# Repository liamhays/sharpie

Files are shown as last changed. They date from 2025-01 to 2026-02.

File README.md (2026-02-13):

# Sharpie
Sharpie is a RP2350-based development board for Sharp color (not
monochrome!) memory-in-pixel (MiP) displays, using only the PIO
peripheral. It was originally built for the Sharp LS021B7DD02 display,
but should be compatible with any color MiP device made by Sharp. For
in-depth documentation and discussion, see the relevant blog posts [on
my website](https://cryothene.neocities.org).

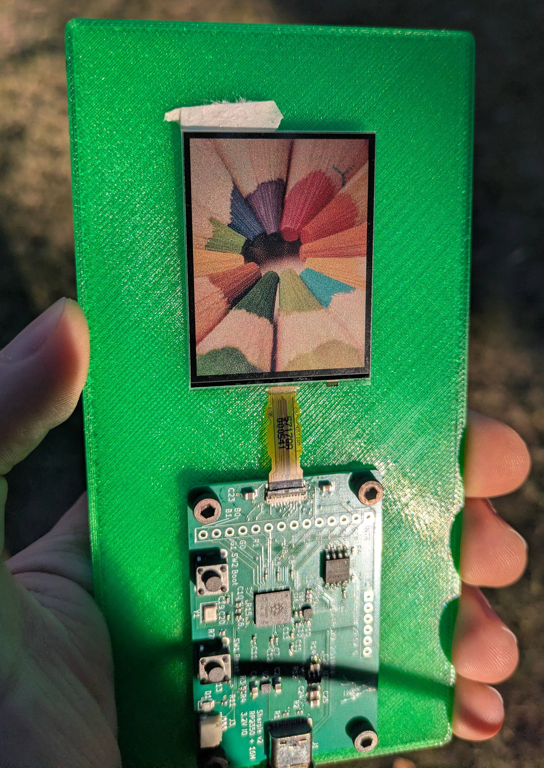
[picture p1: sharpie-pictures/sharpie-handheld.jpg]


Sharpie [plays](https://www.youtube.com/watch?v=W0dpXhKVE6Y)
[video](https://www.youtube.com/watch?v=7nzBJTZcFak) too!

## Repo contents
- `sharpie-cad`: a little bit of FreeCAD for a display/board carrier
- `sharpie-documents`: the LS021B7DD02 datasheet link on DigiKey is
  broken, this is the latest version from when it used to work
- `sharpie-formatter`: an image formatter written in Rust that can
  dither and format images to binary data, ready to be written
  directly to the display
- `sharpie-hw`: the original revision of the hardware, with an extra
  voltage regulator and the display connector wired backward
- `sharpie-hw-rev2`: the second revision of the hardware, with that
  extra regulator removed and the display connector wired correctly
  (this is the revision that works)
- `sharpie-pictures`: assorted pictures of the project
- `sharpie-rp2040`: initial proof-of-concept for the PIO display
  interface, running on an RP2040 instead of an RP2350.
- `sharpie-sw`: the current demo software for a Sharpie rev2 board,
  and a nearly perfect **reference implementation** for using this
  work with a display
- `sharpie-usb-display`: an actually useful demo, which streams 4:3
  video over USB to a Sharpie board
- `vdp-simulator`: some proof-of-concept Rust code for how you could
  make a Sega-inspired tile-based video display processor in software

## Licensing
The hardware in `sharpie-hw` and `sharpie-hw-rev2` is licensed under
the CERN-OHL-W. A copy of this license is in `sharpie-hw-rev2`.

All software in this repository is licensed under the GPLv3, available
in `LICENSE` in the root.

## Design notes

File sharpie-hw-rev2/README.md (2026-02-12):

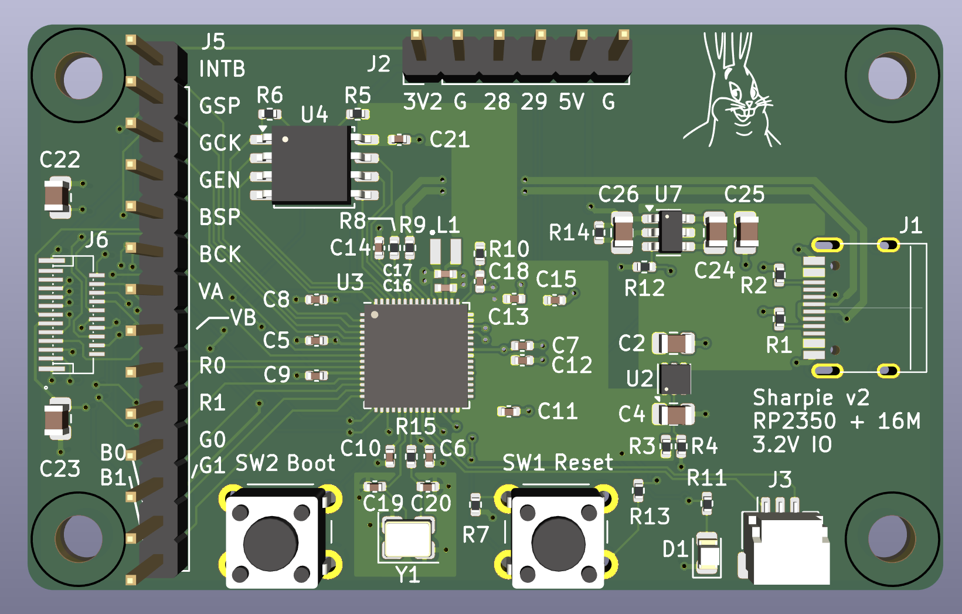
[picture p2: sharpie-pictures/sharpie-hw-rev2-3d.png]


This directory exists because I wired the connector backwards on the
original Sharpie board. Rev2 of the board also drops the 3.3V regulator,
adds the RESET pull-up that I forgot, and has a nicer looking board.

There is a lot of duplicate stuff in this directory, because I copied
straight from the original sharpie-hw design.

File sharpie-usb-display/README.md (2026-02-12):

# sharpie-usb-display
This is probably the ultimate Sharpie demo, a set of client and host
software to stream video in real time to Sharpie (and its display)
over USB. The host uses GStreamer to decode and convert a video,
then dithers and formats video frames before zstd-compressing them and
writing them to the client's USB endpoint. The client receives frames,
decompresses them, and puts them on the display.

This requires both cores on the RP2350. Instrumentation code is in
both source files if you're curious about how much time various steps
in the process require.

The host needs to be run with `--release` because the dithering is
slow (20-50 ms) in debug, but 4 ms in release. It also can't play
Matroska files, for some reason, probably because it uses a simple
GStreamer host pipeline that expects audio and video to be present
from early on.

# Notes
## Compression and transfer
lz4 is a good compression algorithm, but it doesn't get frames small
enough. zstd does, though, and it still runs plenty fast on the
RP2350.

## Video
I accidentally turned the system clock up to 200 MHz, and then I
realized that the display was still working even though the PIO and
PWM were running significantly faster. Running the PIO faster reduces
the time it takes to fill the display with new data, which helps
reduce screen tearing. Increasing the clock to 200 MHz means the
screen can theoretically run at ~24.8 fps, which beats the average
movie frame rate of 24 fps. The problem is that the USB link is
limited to about 22 fps, and increasing the frame rate also makes
flicker a little more visible (to my eyes, at least). From my testing,
the data link can always handle 21 fps, but no higher.

One change to potentially make in the future is some sort of smarter
dither algorithm that only dithers in changed regions, or something,
to reduce full-frame flicker. I think the reason that dither is so
visible is because the dithering causes every single frame to have
almost entirely different pixels. I'd also like to replace the
dithering with a SIMD implementation, and maybe these changes could
happen simultaneously.

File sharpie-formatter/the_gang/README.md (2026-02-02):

# ryuuko
These are various versions of a screenshot from an early episode of
[Kill la Kill](https://myanimelist.net/anime/18679/Kill_la_Kill), cropped
to 4:3, rescaled, and dithered. I
made these by hand with various odd tools (mostly
[dither](https://gitlab.com/efronlicht/dither)) before `sharpie-formatter`
could do all the image processing by itself, and they're here
for archival purposes.

Note in particular the dithering variants under `processed/`. I settled
on Floyd-Steinberg for `sharpie-formatter` specifically because of how
it preserved the detail in this frame.

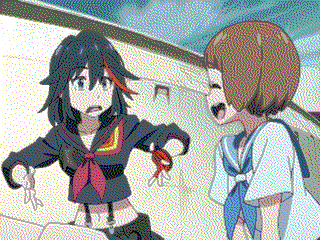
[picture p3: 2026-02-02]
sharpie-formatter/the_gang/processed/jarvis_64color.png

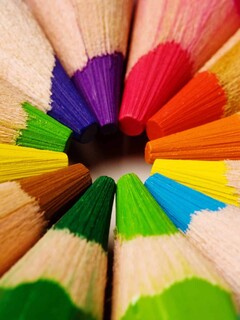
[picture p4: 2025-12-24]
sharpie-sw/pencils.jpg

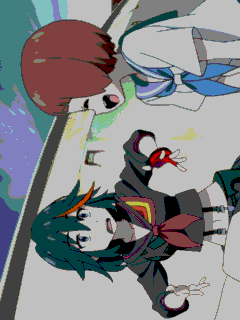
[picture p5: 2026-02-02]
sharpie-formatter/the_gang/processed/the_gang_default_formatter.png

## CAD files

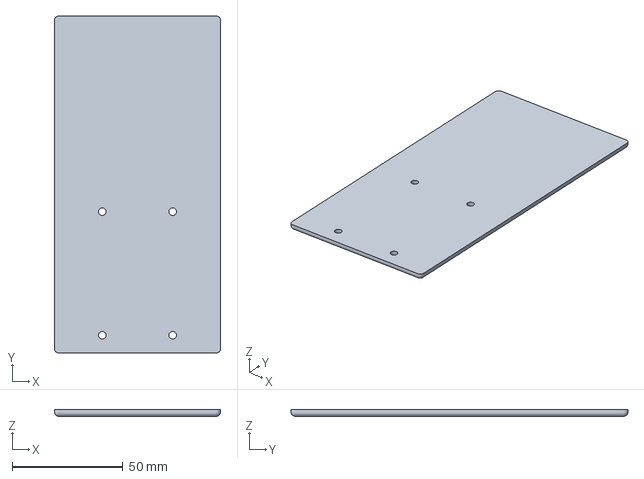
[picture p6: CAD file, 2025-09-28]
sharpie-cad/sharpie-carrier-Body.3mf
75.0 x 152.0 x 3.00 mm

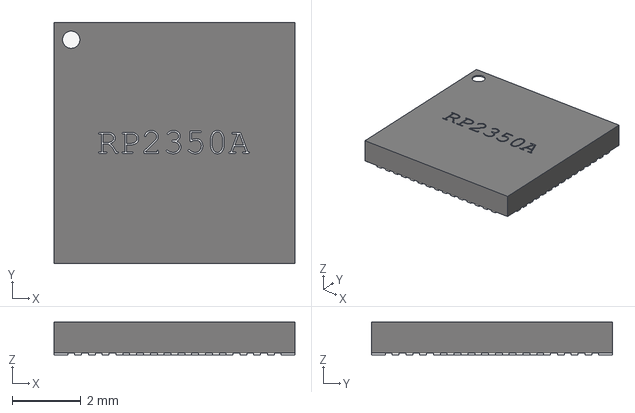
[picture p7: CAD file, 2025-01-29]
sharpie-hw-rev2/RP2350_QFN60.step
7.00 x 7.00 x 0.95 mm

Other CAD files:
sharpie-cad/sharpie-carrier.FCStd

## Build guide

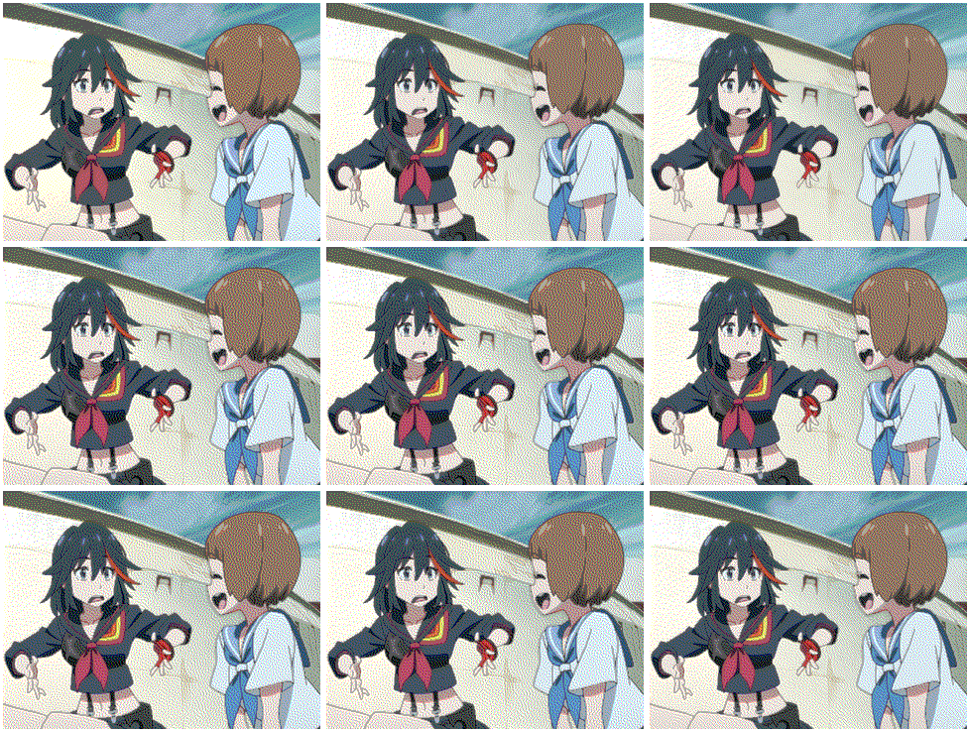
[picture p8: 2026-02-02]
sharpie-formatter/the_gang/processed/64_color_montage.png

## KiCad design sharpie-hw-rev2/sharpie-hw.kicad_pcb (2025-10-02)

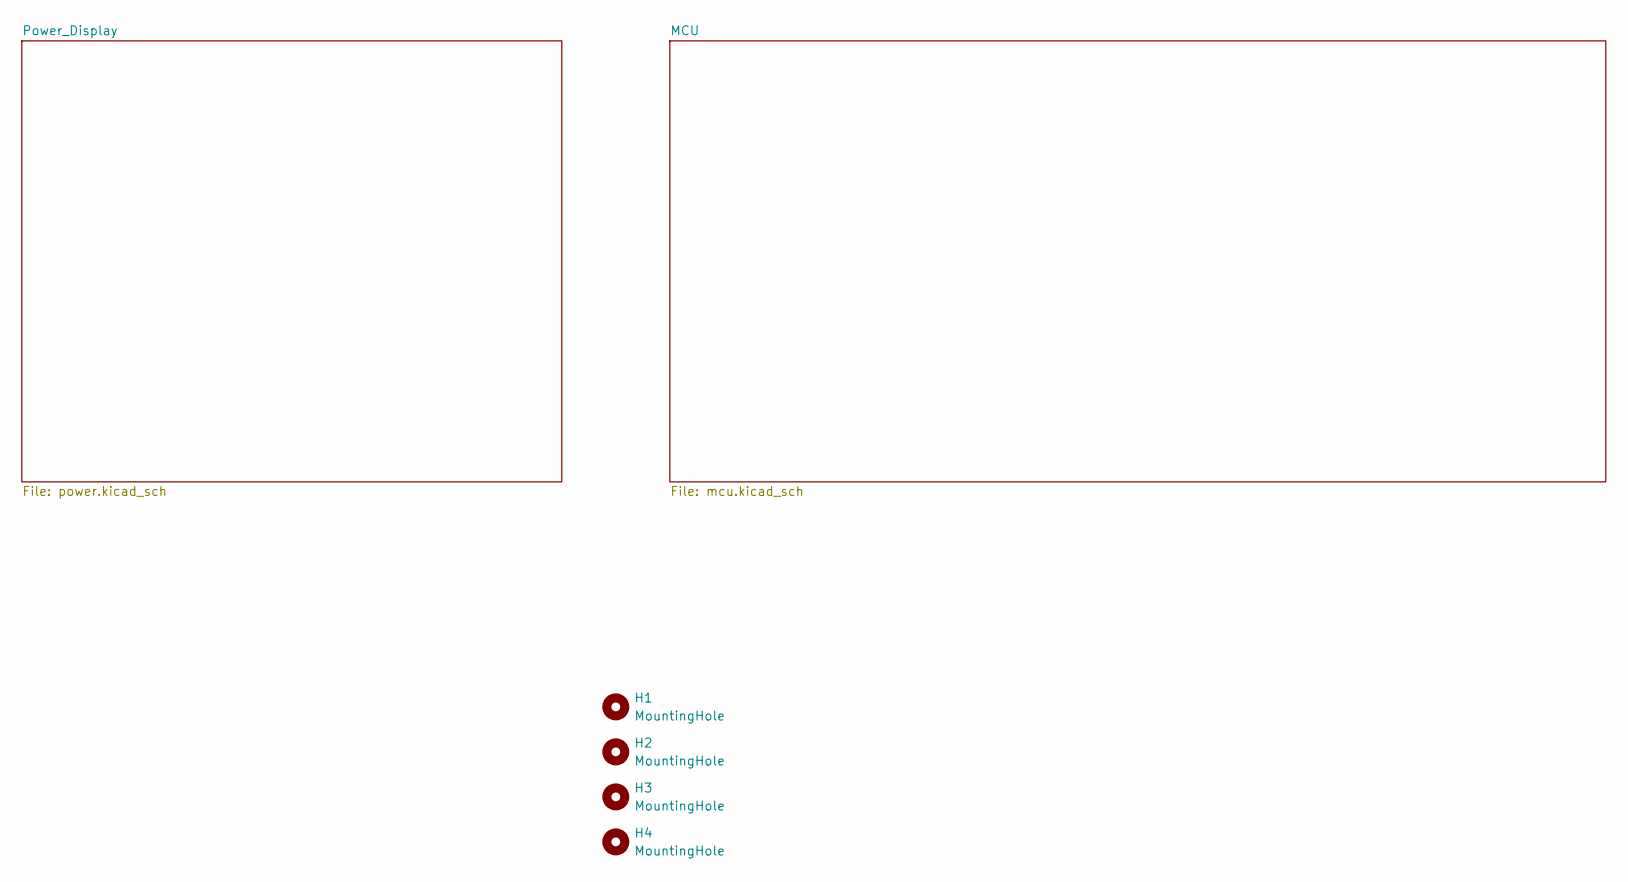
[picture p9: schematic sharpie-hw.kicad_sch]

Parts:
H1, H2, H3, H4: MountingHole; MountingHole_3.2mm_M3

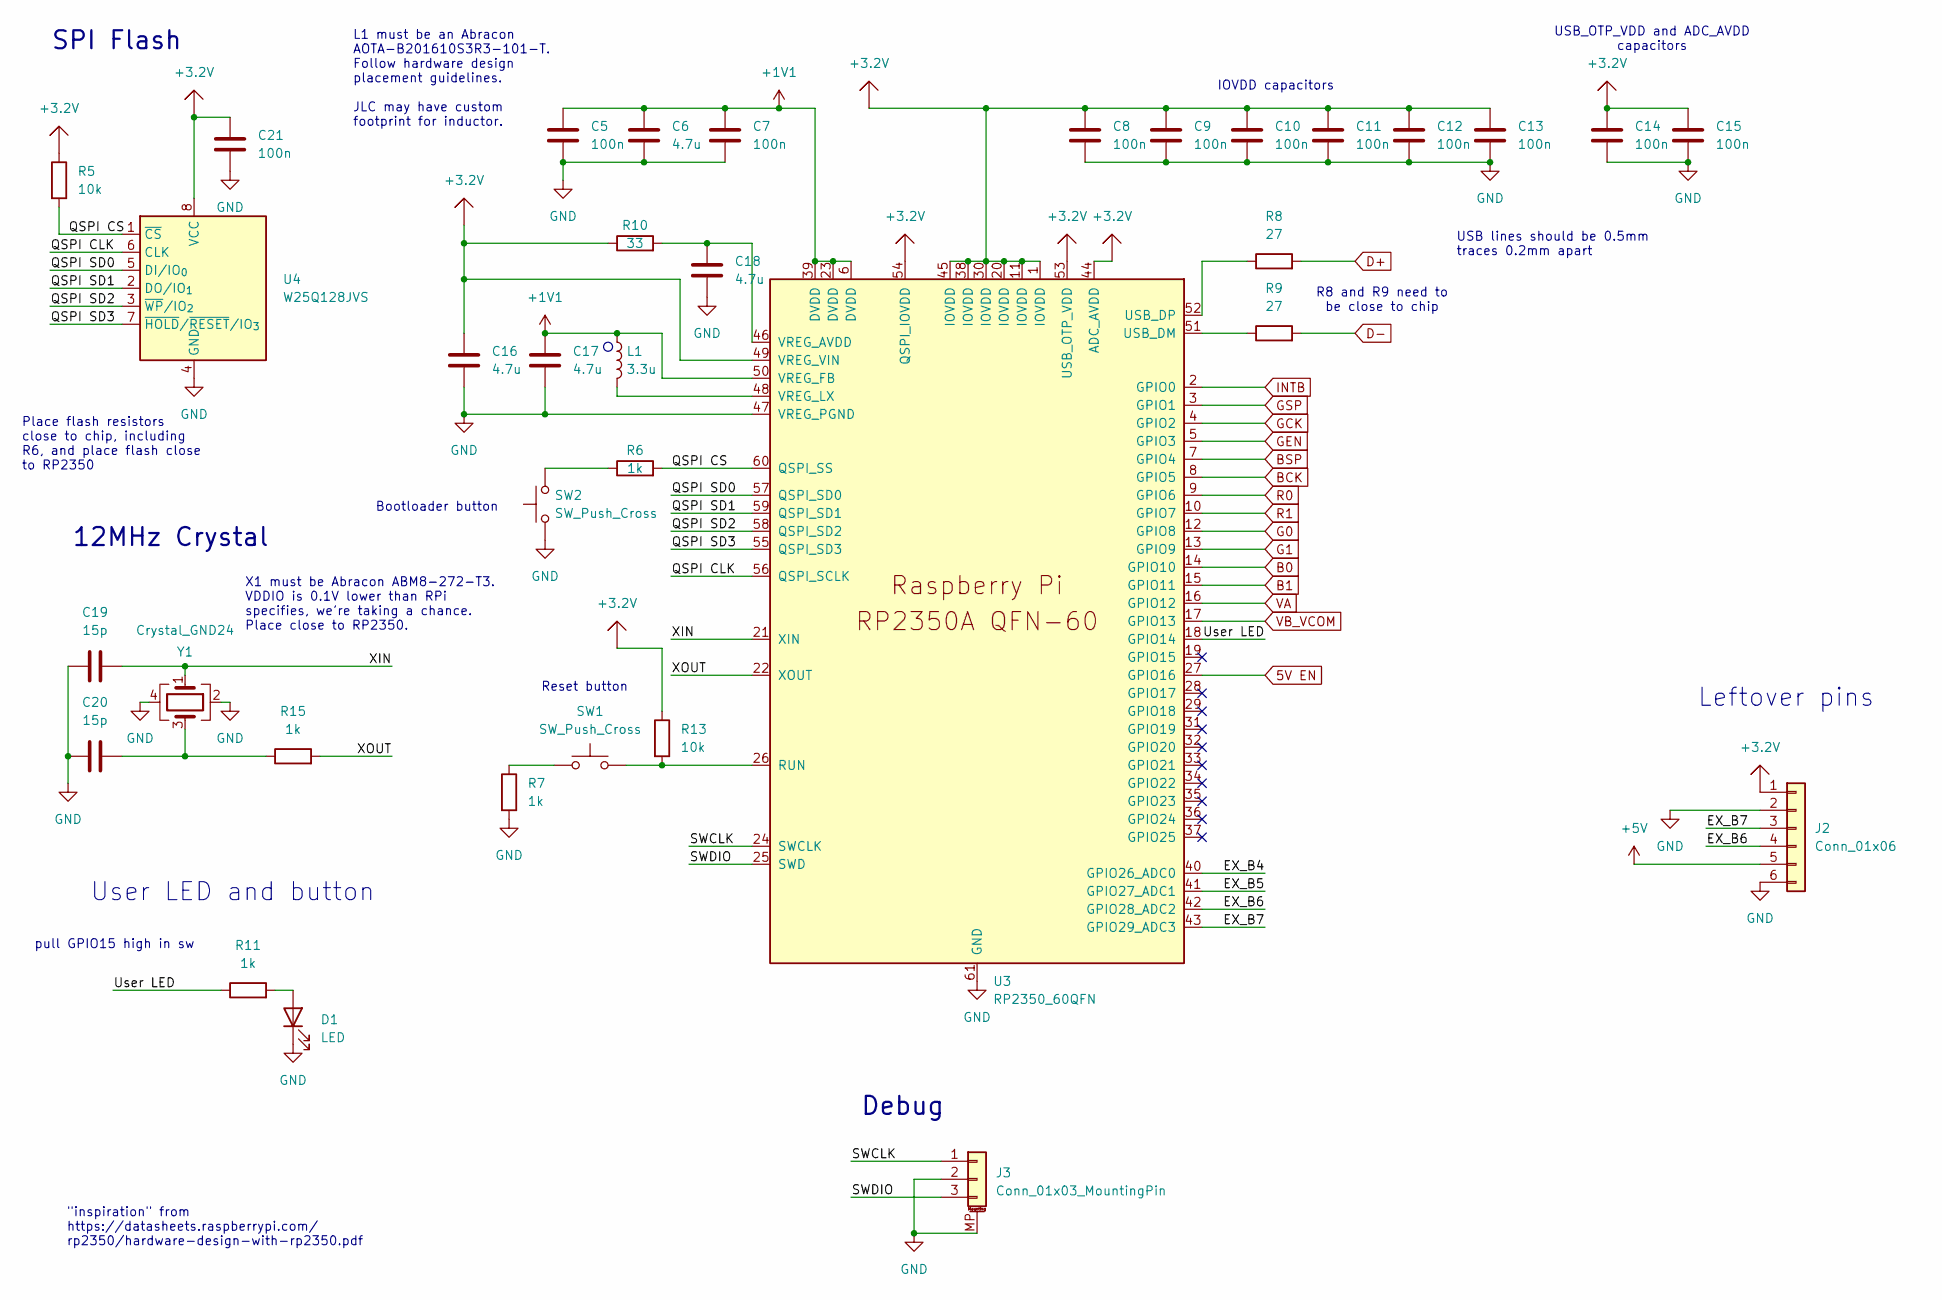
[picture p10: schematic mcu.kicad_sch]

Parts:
C5, C7, C8, C9, C10, C11, C12, C13, C14, C15, C21: 100n; C_0402_1005Metric; JLCPCB Part # C1525
C6, C18: 4.7u; C_0402_1005Metric; JLCPCB Part # C23733
C16, C17: 4.7u; C_0402_1005Metric_small_pads; JLCPCB Part # C23733
C19, C20: 15p; C_0402_1005Metric; JLCPCB Part # C1548
D1: LED; LED_0805_2012Metric; JLCPCB Part # C2297
J2: Conn_01x06; PinHeader_1x06_P2.54mm_Vertical
J3: Conn_01x03_MountingPin; JST_SH_SM03B-SRSS-TB_1x03-1MP_P1.00mm_Horizontal; JLCPCB Part # C160403
L1: 3.3u; L_pol_2016; JLCPCB Part # C42411119
R5, R13: 10k; R_0402_1005Metric; JLCPCB Part # C25744
R6, R7, R11, R15: 1k; R_0402_1005Metric; JLCPCB Part # C11702
R8, R9: 27; R_0402_1005Metric; JLCPCB Part # C25156
R10: 33; R_0402_1005Metric; JLCPCB Part # C25105
SW1, SW2: SW_Push_Cross; SW_PUSH_6mm
U3: RP2350_60QFN; RP2350-QFN-60-1EP_7x7_P0.4mm_EP3.4x3.4mm_ThermalVias; JLCPCB Part # C42411118
U4: W25Q128JVS; SOIC-8_5.3x5.3mm_P1.27mm; JLCPCB Part # C97521
Y1: Crystal_GND24; Crystal_SMD_3225-4Pin_3.2x2.5mm; JLCPCB Part # C20625731

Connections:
5V EN: U3.27 (GPIO16); also elsewhere on the board
+1V1: C5.1, C6.1, C7.1, C17.1, L1.1, U3.6 (DVDD), U3.23 (DVDD), U3.39 (DVDD), U3.50 (VREG_FB)
+3.2V: C8.1, C9.1, C10.1, C11.1, C12.1, C13.1, C14.1, C15.1, C16.1, C21.1, J2.1, R5.1, R10.1, R13.1, U3.1 (IOVDD), U3.11 (IOVDD), U3.20 (IOVDD), U3.30 (IOVDD), U3.38 (IOVDD), U3.44 (ADC_AVDD), U3.45 (IOVDD), U3.49 (VREG_VIN), U3.53 (USB_OTP_VDD), U3.54 (QSPI_IOVDD), U4.8 (VCC); also elsewhere on the board
+5V: J2.5; also elsewhere on the board
/MCU/EX_B4: U3.40 (GPIO26_ADC0)
/MCU/EX_B5: U3.41 (GPIO27_ADC1)
/MCU/EX_B6: J2.4, U3.42 (GPIO28_ADC2)
/MCU/EX_B7: J2.3, U3.43 (GPIO29_ADC3)
/MCU/QSPI CLK: U3.56 (QSPI_SCLK), U4.6 (CLK)
/MCU/QSPI CS: R5.2, R6.2, U3.60 (QSPI_SS), U4.1 (~CS)
/MCU/QSPI SD0: U3.57 (QSPI_SD0), U4.5 (DI/IO_{0})
/MCU/QSPI SD1: U3.59 (QSPI_SD1), U4.2 (DO/IO_{1})
/MCU/QSPI SD2: U3.58 (QSPI_SD2), U4.3 (~WP/IO_{2})
/MCU/QSPI SD3: U3.55 (QSPI_SD3), U4.7 (~HOLD/~RESET/IO_{3})
/MCU/SWCLK: J3.1, U3.24 (SWCLK)
/MCU/SWDIO: J3.3, U3.25 (SWD)
/MCU/User LED: R11.1, U3.18 (GPIO14)
/MCU/XIN: C19.2, U3.21 (XIN), Y1.1
/MCU/XOUT: R15.2, U3.22 (XOUT)
B0: U3.14 (GPIO10); also elsewhere on the board
B1: U3.15 (GPIO11); also elsewhere on the board
BCK: U3.8 (GPIO5); also elsewhere on the board
BSP: U3.7 (GPIO4); also elsewhere on the board
D+: R8.2; also elsewhere on the board
D-: R9.2; also elsewhere on the board
G0: U3.12 (GPIO8); also elsewhere on the board
G1: U3.13 (GPIO9); also elsewhere on the board
GCK: U3.4 (GPIO2); also elsewhere on the board
GEN: U3.5 (GPIO3); also elsewhere on the board
GND: C5.2, C6.2, C7.2, C8.2, C9.2, C10.2, C11.2, C12.2, C13.2, C14.2, C15.2, C16.2, C17.2, C18.2, C19.1, C20.1, C21.2, D1.1 (K), J2.2, J2.6, J3.2, J3.MP (MountPin), R7.2, SW2.1, U3.47 (VREG_PGND), U3.61 (GND), U4.4 (GND), Y1.2, Y1.4; also elsewhere on the board
GSP: U3.3 (GPIO1); also elsewhere on the board
INTB: U3.2 (GPIO0); also elsewhere on the board
unnamed: C20.2, R15.1, Y1.3
unnamed: D1.2 (A), R11.2
unnamed: R6.1, SW2.2
unnamed: R7.1, SW1.1
unnamed: R13.2, SW1.2, U3.26 (RUN)
unnamed: R9.1, U3.51 (USB_DM)
unnamed: R8.1, U3.52 (USB_DP)
unnamed: C18.1, R10.2, U3.46 (VREG_AVDD)
unnamed: L1.2, U3.48 (VREG_LX)
R0: U3.9 (GPIO6); also elsewhere on the board
R1: U3.10 (GPIO7); also elsewhere on the board
VA: U3.16 (GPIO12); also elsewhere on the board
VB_VCOM: U3.17 (GPIO13); also elsewhere on the board

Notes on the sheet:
Leftover pins
L1 must be an Abracon AOTA-B201610S3R3-101-T. Follow hardware design placement guidelines. JLC may have custom footprint for inductor.
IOVDD capacitors
Place flash resistors close to chip, including R6, and place flash close to RP2350
Reset button
User LED and button
12MHz Crystal
Bootloader button
"inspiration" from https://datasheets.raspberrypi.com/ rp2350/hardware-design-with-rp2350.pdf
pull GPIO15 high in sw
SPI Flash
USB lines should be 0.5mm traces 0.2mm apart
Debug
USB_OTP_VDD and ADC_AVDD capacitors
X1 must be Abracon ABM8-272-T3. VDDIO is 0.1V lower than RPi specifies, we're taking a chance. Place close to RP2350.
R8 and R9 need to be close to chip

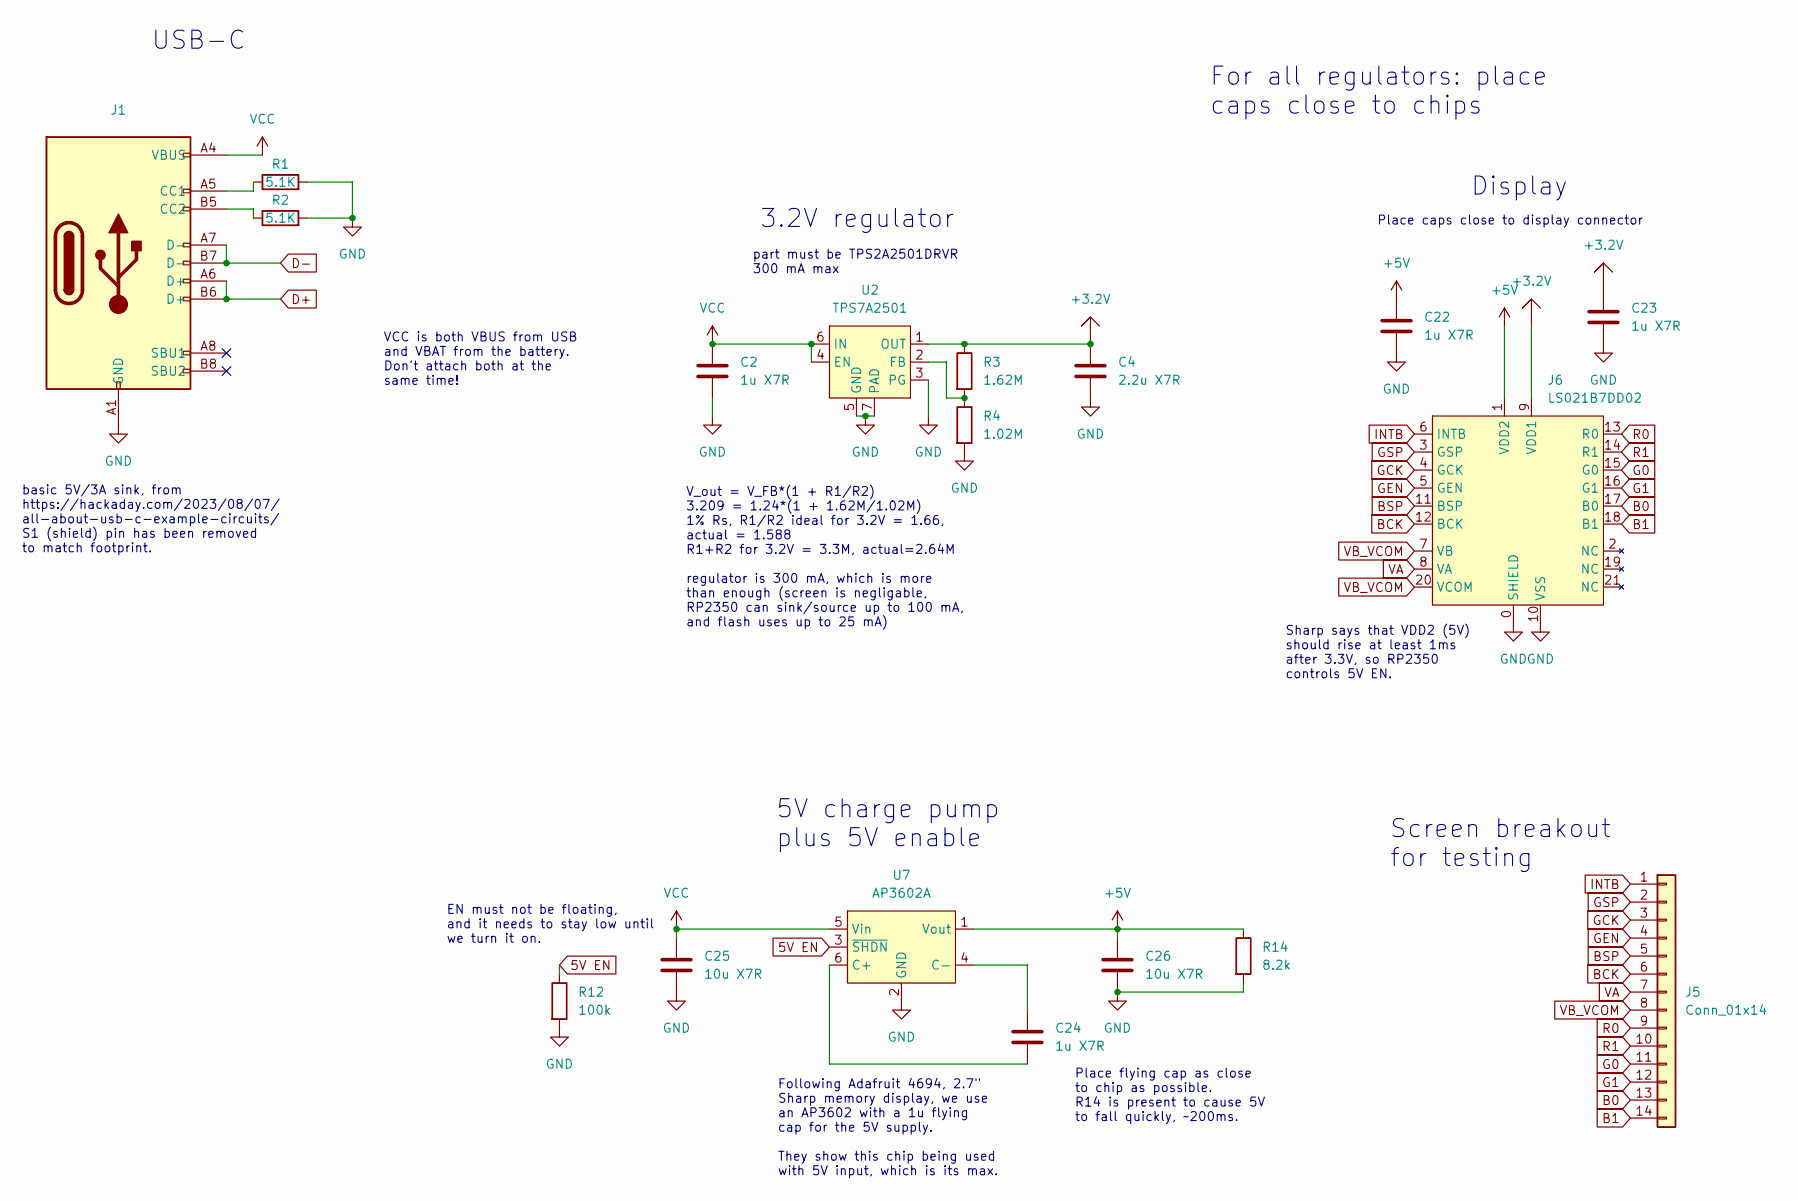
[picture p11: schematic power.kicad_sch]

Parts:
C2, C22, C23, C24: 1u X7R; C_0805_2012Metric; JLCPCB Part # C28323
C4: 2.2u X7R; C_0805_2012Metric; JLCPCB Part # C377773
C25, C26: 10u X7R; C_0805_2012Metric; JLCPCB Part # C15850
J1: TYPE-C-31-M-12; JLCPCB Part # C165948
J5: Conn_01x14; PinHeader_1x14_P2.54mm_Vertical
J6: LS021B7DD02; FPC-SMD_21P-P0.30-503566-2102
R1, R2: 5.1K; R_0402_1005Metric; JLCPCB Part # C25905
R3: 1.62M; R_0402_1005Metric; JLCPCB Part # C166525
R4: 1.02M; R_0402_1005Metric; JLCPCB Part # C26084
R12: 100k; R_0402_1005Metric; JLCPCB Part # C25741
R14: 8.2k; R_0402_1005Metric; JLCPCB Part # C25924
U2: TPS7A2501; WSON-6-1EP_2x2mm_P0.65mm_EP1x1.6mm_ThermalVias; JLCPCB Part # C2864326
U7: AP3602A; SOT-23-6; JLCPCB Part # C460358

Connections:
5V EN: R12.1, U7.3 (~SHDN); also elsewhere on the board
+3.2V: C4.1, C23.1, J6.9 (VDD1), R3.1, U2.1 (OUT); also elsewhere on the board
+5V: C22.1, C26.1, J6.1 (VDD2), R14.1, U7.1 (Vout); also elsewhere on the board
B0: J5.13, J6.17 (B0); also elsewhere on the board
B1: J5.14, J6.18 (B1); also elsewhere on the board
BCK: J5.6, J6.12 (BCK); also elsewhere on the board
BSP: J5.5, J6.11 (BSP); also elsewhere on the board
D+: J1.A6 (D+), J1.B6 (D+); also elsewhere on the board
D-: J1.A7 (D-), J1.B7 (D-); also elsewhere on the board
G0: J5.11, J6.15 (G0); also elsewhere on the board
G1: J5.12, J6.16 (G1); also elsewhere on the board
GCK: J5.3, J6.4 (GCK); also elsewhere on the board
GEN: J5.4, J6.5 (GEN); also elsewhere on the board
GND: C2.2, C4.2, C22.2, C23.2, C25.2, C26.2, J1.A1 (GND), J1.A12 (GND), J1.B1 (GND), J1.B12 (GND), J6.0 (SHIELD), J6.10 (VSS), R1.2, R2.2, R4.2, R12.2, R14.2, U2.3 (PG), U2.5 (GND), U2.7 (PAD), U7.2 (GND); also elsewhere on the board
GSP: J5.2, J6.3 (GSP); also elsewhere on the board
INTB: J5.1, J6.6 (INTB); also elsewhere on the board
unnamed: J1.A5 (CC1), R1.1
unnamed: J1.B5 (CC2), R2.1
unnamed: R3.2, R4.1, U2.2 (FB)
unnamed: C24.1, U7.6 (C+)
unnamed: C24.2, U7.4 (C-)
R0: J5.9, J6.13 (R0); also elsewhere on the board
R1: J5.10, J6.14 (R1); also elsewhere on the board
VA: J5.7, J6.8 (VA); also elsewhere on the board
VB_VCOM: J5.8, J6.7 (VB), J6.20 (VCOM); also elsewhere on the board
VCC: C2.1, C25.1, J1.A4 (VBUS), J1.A9 (VBUS), J1.B4 (VBUS), J1.B9 (VBUS), U2.4 (EN), U2.6 (IN), U7.5 (Vin)

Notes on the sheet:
basic 5V/3A sink, from https://hackaday.com/2023/08/07/ all-about-usb-c-example-circuits/ S1 (shield) pin has been removed to match footprint.
Place flying cap as close to chip as possible. R14 is present to cause 5V to fall quickly, ~200ms.
V_out = V_FB*(1 + R1/R2) 3.209 = 1.24*(1 + 1.62M/1.02M) 1% Rs, R1/R2 ideal for 3.2V = 1.66, actual = 1.588 R1+R2 for 3.2V = 3.3M, actual=2.64M regulator is 300 mA, which is more than enough (screen is negligable, RP2350 can sink/source up to 100 mA, and flash uses up to 25 mA)
EN must not be floating, and it needs to stay low until we turn it on.
3.2V regulator
Display
VCC is both VBUS from USB and VBAT from the battery. Don't attach both at the same time!
Place caps close to display connector
For all regulators: place caps close to chips
part must be TPS2A2501DRVR 300 mA max
5V charge pump plus 5V enable
Following Adafruit 4694, 2.7" Sharp memory display, we use an AP3602 with a 1u flying cap for the 5V supply. They show this chip being used with 5V input, which is its max.
Sharp says that VDD2 (5V) should rise at least 1ms after 3.3V, so RP2350 controls 5V EN.
Screen breakout for testing
USB-C

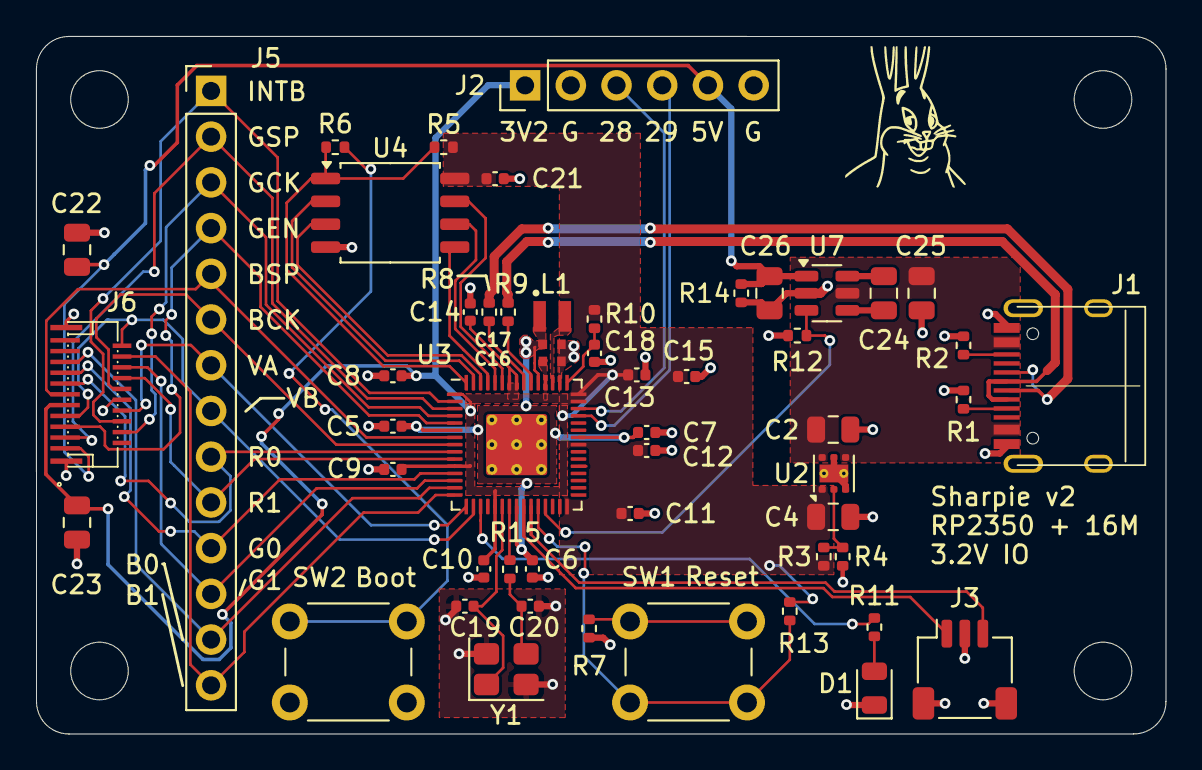
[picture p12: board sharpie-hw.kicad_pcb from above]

Board: 2 copper layers, 62.8 x 38.8 mm, 57 parts (0 on the bottom side), 49 nets.

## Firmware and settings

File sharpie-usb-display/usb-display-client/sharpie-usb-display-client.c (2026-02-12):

#include <stdio.h>
#include <stdlib.h>
#include <string.h>

#include "pico/stdlib.h"
#include "pico/multicore.h"
#include "hardware/clocks.h"
#include "hardware/uart.h"
#include "hardware/pio.h"
#include "hardware/dma.h"
#include "hardware/pwm.h"

#include "sharpie-vertical.pio.h"
#include "sharpie-gen.pio.h"
#include "sharpie-horiz-data.pio.h"
// tinyusb source

#include "RP2350.h"

// tusb_config.h is included by tusb.h. we've configured CMake so that
// it knows to make tusb_config.h available.
#include "bsp/board_api.h"
#include "tusb.h"

#include "zstd.h"

#define BUFSIZE (76800)
#define RUNS (300)

typedef struct compressed_buffer {
  uint8_t data[BUFSIZE];
  uint32_t compressed_size;
} compressed_buffer_t;

// TODO: write directly into the buffers instead of inputbuf
uint8_t inputbuf[BUFSIZE];
compressed_buffer_t compressed_buffer0 = {0};
compressed_buffer_t compressed_buffer1 = {0};
uint8_t framebuffer[BUFSIZE];


// USB RX buffer is 32768, TX buffer is 64

const int led_pin = 14;
const int five_volt_en = 16;
const int va_pin = 12;
const int vb_vcom_pin = 13;

uint pwm_slice;

void error_handler() {
  while (1) {
    gpio_put(led_pin, 1);
    sleep_ms(500);
    gpio_put(led_pin, 0);
    sleep_ms(500);
  }
}


uint vertical_sm = 0;
uint gen_sm = 1;
uint horiz_data_sm = 2;

PIO full_frame_pio = pio0;

uint vertical_offset;
uint gen_offset;
uint horiz_data_offset;


uint32_t global_32bit_zero = 0;
int image_pixels_channel;
int image_pixels_zero_channel;
int compressed_data_copy_channel;

void send_full_frame_image(const unsigned char* source) {
  
  // this DMA stream sends the image, and chains to `image_zero_c`,
  // which sends 120 bytes of zeros to close out the image. a change
  // to make in the future is to include these zeros in the image
  // buffer, so a second stream isn't necessary.
  dma_channel_config image_c = dma_channel_get_default_config(image_pixels_channel);
  channel_config_set_read_increment(&image_c, true); // increment reads
  channel_config_set_write_increment(&image_c, false); // no increment writes (into the FIFO)
  channel_config_set_transfer_data_size(&image_c, DMA_SIZE_32); // four byte transfers (one byte doesn't work)
  channel_config_set_dreq(&image_c, pio_get_dreq(full_frame_pio, horiz_data_sm, true)); // true for sending data to SM
  channel_config_set_chain_to(&image_c, image_pixels_zero_channel); // chain to zero channel to start zero channel when this finishes
  dma_channel_configure(image_pixels_channel, &image_c,
			&full_frame_pio->txf[horiz_data_sm], // destination (TX FIFO of SM 2)
		        source, // source 
			19200, // transfer size = 320*240/4 = 19200
			true); // start now



  dma_channel_config image_zero_c = dma_channel_get_default_config(image_pixels_zero_channel);
  channel_config_set_read_increment(&image_zero_c, false); // just send zeros
  channel_config_set_write_increment(&image_zero_c, false); // write into FIFO
  channel_config_set_transfer_data_size(&image_zero_c, DMA_SIZE_32);
  channel_config_set_dreq(&image_zero_c, pio_get_dreq(full_frame_pio, horiz_data_sm, true));
  dma_channel_configure(image_pixels_zero_channel, &image_zero_c,
			&full_frame_pio->txf[horiz_data_sm],
			&global_32bit_zero,
			120/4,
			false); // wait for chain start


  
  // transmit image
  full_frame_pio->irq_force = 0b1;
}

void init_full_frame_pio() {
  // add programs for the full-frame (no partial update) PIO
  vertical_offset = pio_add_program(full_frame_pio, &sharpie_vertical_program);
  if (vertical_offset < 0) {
    printf("failed to add sharpie_vertical_program\n");
    error_handler();
  }
  
  // init GEN state machine
  gen_offset = pio_add_program(full_frame_pio, &sharpie_gen_program);
  if (gen_offset < 0) {
    printf("failed to add sharpie_gen_program\n");
    error_handler();
  }
  
  
  // init horiz/data state machine
  horiz_data_offset = pio_add_program(full_frame_pio,
				      &sharpie_horiz_data_program);
  if (horiz_data_offset < 0) {
    printf("failed to add sharpie_horiz_data_program\n");
    error_handler();
  }

}

void reset_full_frame_pio() {
  // init all three state machines. we would prefer to not do this
  // every time but it takes a decent amount of consideration to make that work.

  // INTB on 0, GSP on 1, GCK on 2
  sharpie_vertical_pio_init(full_frame_pio, vertical_sm, vertical_offset, 0);
  // GEN on pin 3, start state machine
  sharpie_gen_pio_init(full_frame_pio, gen_sm, gen_offset, 3);
  // BSP on pin 4, BCK on pin 5, data from pin 6 to 11 inclusive
  sharpie_horiz_data_pio_init(full_frame_pio, horiz_data_sm, horiz_data_offset, 4, 6);
  
  // charge the vertical state machine, it's waiting for irq 0
  // the number you put in its FIFO is the number of times the loop
  // will run, minus 1
  pio_sm_put(full_frame_pio, vertical_sm, 321); // run 321 times for 648 h/l total
  
  // GEN: run 5 times (counter value + 1)
  pio_sm_put(full_frame_pio, gen_sm, 639); // this should be 639 for 640 high pulses
  pio_sm_exec(full_frame_pio, gen_sm, pio_encode_pull(false, false)); // just a basic pull
  pio_sm_exec(full_frame_pio, gen_sm, pio_encode_mov(pio_x, pio_osr)); // mov x, osr
  // GEN counter is now charged
  
  // horiz-data: charge X, make a backup in ISR (unused by any other part of the code)
  pio_sm_put(full_frame_pio, horiz_data_sm, 59); // we'll get a total of 2(x+1)+4 h/l so this should be 59 => 2(59+1)+4 = 124
  pio_sm_exec(full_frame_pio, horiz_data_sm, pio_encode_pull(false, false));  // pull
  pio_sm_exec(full_frame_pio, horiz_data_sm, pio_encode_out(pio_isr, 32)); // out isr, 32 (make backup of counter value and clear OSR for autopull)
  pio_sm_exec(full_frame_pio, horiz_data_sm, pio_encode_mov(pio_x, pio_isr)); // mov x, isr (load X with counter)
  // charge Y for total loop counter
  pio_sm_put(full_frame_pio, horiz_data_sm, 640); // should be 640 for 641 loops (see 6-3-2, the last loop has data all zeros, which is why we have a chained DMA channel below)
  pio_sm_exec(full_frame_pio, horiz_data_sm, pio_encode_pull(false, false)); // pull
  pio_sm_exec(full_frame_pio, horiz_data_sm, pio_encode_out(pio_y, 32)); // out y, 32 (also clears OSR)

  // restart all state machine clocks
  //pio_clkdiv_restart_sm_mask(full_frame_pio, 0b111); // restart state machines
  
}



const uint32_t sys_clock_hz = 200000000;
// we know exactly how the PIO works, so we can use this for an easy
// final delay in the core1 loop
const uint32_t one_gck_hl_us = (1./((float)sys_clock_hz/3100.)) * 4e6;


int data_ready_doorbell;
// the framebuffer ID with the newest data in it
volatile int newest_compressed_buffer = 0;

void core1_entry() {
  CoreDebug->DEMCR |= CoreDebug_DEMCR_TRCENA_Msk;
  
  DWT->CTRL |= DWT_CTRL_CYCCNTENA_Msk;

  char str[100];
  uint32_t count = 0;
  while (true) {
    if (multicore_doorbell_is_set_current_core(data_ready_doorbell)) {
      //gpio_put(led_pin, !gpio_get(led_pin));
      multicore_doorbell_clear_current_core(data_ready_doorbell);

      //multicore_doorbell_set_other_core(data_processing_doorbell);
      DWT->CYCCNT = 0;
      uint32_t compressed_size = 0;
      size_t dsize = 0;
      // the minute the frame size drops down to like 2000 bytes, the
      // screen goes awry, because the PIO is getting reset during a
      // frame (data transfer outpaces data transmission).
      if (newest_compressed_buffer == 0) {
	dsize = ZSTD_decompress(framebuffer, 76800,
				compressed_buffer0.data,
				compressed_buffer0.compressed_size);

	compressed_size = compressed_buffer0.compressed_size;
      } else if (newest_compressed_buffer == 1) {
	dsize = ZSTD_decompress(framebuffer, 76800,
				compressed_buffer1.data,
				compressed_buffer1.compressed_size);
	compressed_size = compressed_buffer1.compressed_size;
      }
      
      uint32_t c = DWT->CYCCNT;
      // if we get a really short frame, the decompression time is so
      // low that we end up resetting the PIO during a frame, and the
      // screen goes dark. if we instead always make sure that the PIO
      // is done before resetting it, then the screen always holds the
      // correct frame.
      while (dma_channel_is_busy(image_pixels_channel) ||
	     dma_channel_is_busy(image_pixels_zero_channel));
      // after the DMA ends, we have five GCK h/ls to wait for. add
      // one more for good measure
      sleep_us(one_gck_hl_us*6);
      reset_full_frame_pio();
      send_full_frame_image(framebuffer);

      /*sprintf(str, "frame %lu: decompression time for %lu bytes=>%lu bytes: %f\r\n",
	      count, compressed_size, dsize, ((float)c/200e6));
      uart_puts(uart1, str);*/
      //count++;
      //multicore_doorbell_clear_other_core(data_processing_doorbell);
    }
  }

}

void main() {
  // there doesn't appear to be any issues at 150 MHz except for
  // excessive screen tearing sometimes. upping this to 200 MHz means
  // that the display transmission is faster, so tearing is less
  // visible (also, that much of a change should put the display
  // signals out of spec, but that doesn't seem to happen).

  set_sys_clock_hz(sys_clock_hz, true);
  // enable cycle counter
  CoreDebug->DEMCR |= CoreDebug_DEMCR_TRCENA_Msk;
  
  DWT->CTRL |= DWT_CTRL_CYCCNTENA_Msk;

  // init multicore
  data_ready_doorbell = multicore_doorbell_claim_unused((1 << NUM_CORES) - 1, true);
  multicore_doorbell_clear_current_core(data_ready_doorbell);
  
  multicore_launch_core1(core1_entry);
  
  // init display stuff
  gpio_init(five_volt_en);
  gpio_set_dir(five_volt_en, GPIO_OUT);

  gpio_init(led_pin);
  gpio_set_dir(led_pin, GPIO_OUT);

  // this is a shortened version of the init procedure in sharpie-sw
  gpio_put(five_volt_en, 1);
  sleep_ms(3);

  pwm_slice = pwm_gpio_to_slice_num(va_pin); // channel 6A (slice 6)

  // using pwm_config doesn't seem to work
  gpio_set_function(va_pin, GPIO_FUNC_PWM);
  gpio_set_function(vb_vcom_pin, GPIO_FUNC_PWM);
  pwm_set_clkdiv(pwm_slice, 250);
  int wrap = 10000;
  pwm_set_wrap(pwm_slice, wrap);
  // VB/VCOM needs to start first, with VA 180 degrees out of phase,
  // so we set the counter halfway so that the outputs are initially
  // on. the second output is also inverted to make the phase shift.
  pwm_set_counter(pwm_slice, wrap/2);
  pwm_set_chan_level(pwm_slice, PWM_CHAN_A, wrap/2);
  pwm_set_chan_level(pwm_slice, PWM_CHAN_B, wrap/2);
  // invert output B (VB/VCOM)
  pwm_set_output_polarity(pwm_slice, false, true);
  pwm_set_enabled(pwm_slice, true);

  // wait at least two VB/VCOM cycles (at 60 Hz one cycle is 16 ms)
  //
  // Datasheet shows at least 1.5 cycles before sending data
  sleep_ms(60);

  
  // set up debug uart
  gpio_set_function(26, UART_FUNCSEL_NUM(uart1, 26));
  gpio_set_function(27, UART_FUNCSEL_NUM(uart1, 27));
  uart_init(uart1, 115200);
  uart_puts(uart1, "init\r\n");

  char str[100];

  
  tusb_rhport_init_t dev_init = {
    .role = TUSB_ROLE_DEVICE,
    .speed = TUSB_SPEED_AUTO
  };
  board_init();
  tusb_init(0, &dev_init);

  bool frame_in_progress = false;
  uint32_t count = 0;
  uint32_t compressed_size = 0;
  
  init_full_frame_pio();
  image_pixels_channel = dma_claim_unused_channel(true); // true -> required
  if (image_pixels_channel < 0) {
    printf("failed to claim red dma channel\n");
    error_handler();
  }

  image_pixels_zero_channel = dma_claim_unused_channel(true);
  if (image_pixels_zero_channel < 0) {
    printf("failed to claim red dma zero channel\n");
    error_handler();
  }

  compressed_data_copy_channel = dma_claim_unused_channel(true);
  if (compressed_data_copy_channel < 0) {
    printf("failed to claim compressed data copy channel\n");
    error_handler();
  }

  // reset and send take 61 us
  /*DWT->CYCCNT = 0;
  uint32_t c = DWT->CYCCNT;

  sprintf(str, "finished, took %lu cycles = %f sec\r\n",
		c, ((float)c/sys_clock_hz));
  uart_puts(uart1, str);*/
  
  while (1) {
    tud_task();

    if (!tud_vendor_mounted()) {
      continue;
    }

    uint32_t avail = tud_vendor_available();
    
    if (avail != 0) {

      if (!frame_in_progress) {
	frame_in_progress = true;
	DWT->CYCCNT = 0;
	// read initial 4 byte size value
	compressed_size = 0;
	count = 0;
	// start by reading just the number of bytes in this compressed frame
	count += tud_vendor_read(inputbuf, 4);
	memcpy(&compressed_size, inputbuf, 4);
	/*sprintf(str, "going to read %lu bytes\r\n", compressed_size);
	uart_puts(uart1, str);*/
      }

      // then try to read as many as we can get
      count += tud_vendor_read(inputbuf + count, compressed_size);
      if (count == compressed_size + 4) {

	uint32_t end = DWT->CYCCNT;

	// this loop can always be at most one frame ahead of the
	// decompression loop
	
	if (newest_compressed_buffer == 0) {
	  // if we last wrote to 0, use 1
	  //
	  // note that we don't need to copy the count bytes.
	  //
	  // using DMA here would probably save about 20000 cycles,
	  // for maybe a .1-.2 difference in fps
	  memcpy(compressed_buffer1.data, &inputbuf[4], compressed_size);
	  compressed_buffer1.compressed_size = compressed_size;
	  newest_compressed_buffer = 1;
	  multicore_doorbell_set_other_core(data_ready_doorbell);
	  
	} else if (newest_compressed_buffer == 1) {
	  memcpy(compressed_buffer0.data, &inputbuf[4], compressed_size);
	  compressed_buffer0.compressed_size = compressed_size;
	  newest_compressed_buffer = 0;
	  multicore_doorbell_set_other_core(data_ready_doorbell);
	}
	
	uint32_t after_decomp = DWT->CYCCNT;
	/*sprintf(str, "finished, count = %lu, took %lu cycles = %f bytes/sec\r\n",
		count, end, count/((float)end/sys_clock_hz));
	uart_puts(uart1, str);
	 */
	/*sprintf(str, "after copy: %lu cycles (copy took %lu cycles = %f sec) = %f frames/sec\r\n",
		after_decomp, after_decomp - end, ((float)after_decomp - end)/sys_clock_hz, 1/((float)after_decomp/sys_clock_hz));
	uart_puts(uart1, str);*/
	//uart_default_tx_wait_blocking();

	frame_in_progress = false;
      }
    }
  }

  while(true);
  
}

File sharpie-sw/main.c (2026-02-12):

// There's not very much code in this file, because a lot of the
// display signal complexity is taken care of in the state
// machines. That means, however, that what's in this file is actually
// quite abstract, so I recommend that you get yourself a good
// understanding of how this display works and how my code works
// before you try to modify it. See the Sharpie GitHub repository for
// more information.

#include <stdio.h>
#include <stdlib.h>
#include <string.h>

#include "pico/stdlib.h"
#include "hardware/clocks.h"
#include "hardware/pio.h"
#include "hardware/dma.h"
#include "hardware/pwm.h"
#include "sharpie-vertical.pio.h"
#include "sharpie-gen.pio.h"
#include "sharpie-horiz-data.pio.h"

#include "sharpie-partial-gck.pio.h"
#include "sharpie-partial-intb-gsp.pio.h"
#include "sharpie-partial-gck-end.pio.h"
#include "sharpie-partial-horiz-data.pio.h"

// to generate this image, run `cargo run -- dither-format pencils.jpg
// pencils.raw`, then use xxd to make a header file
#include "pencils.h"

const int led_pin = 14;
const int five_volt_en = 16;
const int va_pin = 12;
const int vb_vcom_pin = 13;


uint pwm_slice;

uint32_t global_32bit_zero = 0;


void error_handler() {
  // super basic error loop that works even when a serial terminal
  // isn't connected
  while (1) {
    gpio_put(led_pin, 1);
    sleep_ms(500);
    gpio_put(led_pin, 0);
    sleep_ms(500);
  }
}



uint vertical_sm = 0;
uint gen_sm = 1;
uint horiz_data_sm = 2;

uint partial_intb_gsp_sm = 0;
uint partial_horiz_data_sm = 1;

uint partial_gck_sm = 0;
uint partial_gck_end_sm = 1;

PIO full_frame_pio = pio0;
PIO intb_gsp_horiz_pio = pio1;
PIO gck_gck_end_pio = pio2;


// "full frame" is not the best name for this, but it works. the full
// frame PIO sends a complete frame instead of a set of partial update
// regions.
void init_full_frame_pio() {
  // add programs for the full-frame (no partial update) PIO
  uint vertical_offset = pio_add_program(full_frame_pio, &sharpie_vertical_program);
  if (vertical_offset < 0) {
    printf("failed to add sharpie_vertical_program\n");
    error_handler();
  }
  
  // init GEN state machine
  uint gen_offset = pio_add_program(full_frame_pio, &sharpie_gen_program);
  if (gen_offset < 0) {
    printf("failed to add sharpie_gen_program\n");
    error_handler();
  }
  
  
  // init horiz/data state machine
  uint horiz_data_offset = pio_add_program(full_frame_pio,
					   &sharpie_horiz_data_program);
  if (horiz_data_offset < 0) {
    printf("failed to add sharpie_horiz_data_program\n");
    error_handler();
  }

  // init all three state machines

  // INTB on 0, GSP on 1, GCK on 2
  sharpie_vertical_pio_init(full_frame_pio, vertical_sm, vertical_offset, 0);
  // GEN on pin 3, start state machine
  sharpie_gen_pio_init(full_frame_pio, gen_sm, gen_offset, 3);
  // BSP on pin 4, BCK on pin 5, data from pin 6 to 11 inclusive
  sharpie_horiz_data_pio_init(full_frame_pio, horiz_data_sm, horiz_data_offset, 4, 6);
  
  // charge the vertical state machine, it's waiting for irq 0
  // the number you put in its FIFO is the number of times the loop
  // will run, minus 1
  pio_sm_put(full_frame_pio, vertical_sm, 321); // run 321 times for 648 h/l total
  
  // GEN: run 5 times (counter value + 1)
  pio_sm_put(full_frame_pio, gen_sm, 639); // this should be 639 for 640 high pulses
  pio_sm_exec(full_frame_pio, gen_sm, pio_encode_pull(false, false)); // just a basic pull
  pio_sm_exec(full_frame_pio, gen_sm, pio_encode_mov(pio_x, pio_osr)); // mov x, osr
  // GEN counter is now charged
  
  // horiz-data: charge X, make a backup in ISR (unused by any other part of the code)
  pio_sm_put(full_frame_pio, horiz_data_sm, 59); // we'll get a total of 2(x+1)+4 h/l so this should be 59 => 2(59+1)+4 = 124
  pio_sm_exec(full_frame_pio, horiz_data_sm, pio_encode_pull(false, false));  // pull
  pio_sm_exec(full_frame_pio, horiz_data_sm, pio_encode_out(pio_isr, 32)); // out isr, 32 (make backup of counter value and clear OSR for autopull)
  pio_sm_exec(full_frame_pio, horiz_data_sm, pio_encode_mov(pio_x, pio_isr)); // mov x, isr (load X with counter)
  // charge Y for total loop counter
  pio_sm_put(full_frame_pio, horiz_data_sm, 640); // should be 640 for 641 loops (see 6-3-2, the last loop has data all zeros, which is why we have a chained DMA channel below)
  pio_sm_exec(full_frame_pio, horiz_data_sm, pio_encode_pull(false, false)); // pull
  pio_sm_exec(full_frame_pio, horiz_data_sm, pio_encode_out(pio_y, 32)); // out y, 32 (also clears OSR)

  // restart all state machine clocks
  pio_clkdiv_restart_sm_mask(full_frame_pio, 0b111); // restart state machines
  
}


// The following macros and variables are predefined examples for
// different kinds of partial updates. The first (no numeric suffix on
// the variable names) skips SKIPS lines, then updates CHANGES
// lines. The second (suffix 2) skips SKIPS lines, updates CHANGES
// lines, skips SKIPS2 lines, then updates CHANGES2 lines. Finally,
// the third group of variables updates CHANGES lines at the very top
// of the screen, then skips SKIPS lines, then updates CHANGES2 lines.
//
// The data DMAed into the horiz/data state machine doesn't need to
// change for these, but if the stream is left incomplete after the
// end of the frame, you have to reset it and possibly the SM as
// well. The data stream is initialized in main().

#define SKIPS (200)
#define CHANGES (19)
#define SKIPS2 (20)
#define CHANGES2 (5)



// GCK control needs -1 for the counter to work correctly in all
// circumstances, due to how the loops in the state machines work.
uint32_t gck_control_data[] = {SKIPS - 1,
			       CHANGES - 1,
			       (320-SKIPS-CHANGES) - 1}; // skip the rest

// number of 1/32 GCK h/ls to wait until the GCK end SM activates
uint32_t gck_end_timeout = 2*32 + // 2 full GCK h/ls at start
  SKIPS*2 + // short GCK h/ls
  (CHANGES*2 + 1)*32 + // 19 changed lines (add 1 extra h/l for the way GCK works)
  (319-SKIPS-CHANGES)*2 + 1; // first skip after changed is 2x as long, but
// the initial 2*32 includes the first line, so we use 319, not 320



// just like before
uint32_t gck_control_data2[] = {SKIPS - 1,
				CHANGES - 1,
				SKIPS2 - 1,
				CHANGES2 - 1,
				(320 - SKIPS - CHANGES - SKIPS2 - CHANGES2) - 1};

// also just like before
uint32_t gck_end_timeout2 = 2*32 +
			    SKIPS*2 +
			    (CHANGES*2 + 1)*32 +
			    SKIPS2*2 +
			    (CHANGES2*2 + 1)*32 +
			    (319 - SKIPS - CHANGES - SKIPS2 - CHANGES2)*2 + 1;


// 0 at the start of a GCK control data block tells the SM to start
// sending changed lines beginning with the first line on the display,
// instead of skipping some quantity.
uint32_t gck_control_data3[] = {0,
				CHANGES - 1,
				SKIPS - 1,
				CHANGES2 - 1,
				(320 - SKIPS - CHANGES - SKIPS2 - CHANGES2) - 1};
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

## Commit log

2025-01-12 Add initial hardware design, probably not complete but close.
    [display.kicad_sch, mcu.kicad_sch, power.kicad_sch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]
2025-01-19 sharpie-hw prototype 1: complete
    [display.kicad_sch, mcu.kicad_sch, power.kicad_sch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]
2025-01-29 Finalize schematic, start PCB, configure manufacturing parameters, and start placing RP2350 components.
    [RP2350_QFN60.step, mcu.kicad_sch, power.kicad_sch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]
2025-02-07 Modify FPC footprint, add alternate USB-C footprint, and commit final (before review) design.
    [mcu.kicad_sch, power.kicad_sch, sharpie-hw.kicad_pcb]
2025-02-12 Add all JLCPCB part numbers and some PCB silkscreens.
    [mcu.kicad_sch, power.kicad_sch, sharpie-hw.kicad_pcb]
2025-02-19 Fix some BOM entries and routing choices.
    [mcu.kicad_sch, power.kicad_sch, sharpie-hw.kicad_pcb]
2025-02-19 Adjust display regulators to match datasheet, so they're now 1u 0805.
    [power.kicad_sch, sharpie-hw.kicad_pcb]
2025-02-23 Adjust orientation of necessary parts for JLCPCB assembly.
    [mcu.kicad_sch, power.kicad_sch, sharpie-hw.kicad_pcb]
2025-02-26 Move to as many JLCPCB basic parts as possible and remove user button.
    [mcu.kicad_sch, power.kicad_sch, sharpie-hw.kicad_pcb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]
2025-02-28 Fix two items: battery connector polarity and AP3602 capacitor polarity.
    [mcu.kicad_sch, power.kicad_sch, sharpie-hw.kicad_pcb]
2025-06-08 Add vdp_simulator with one tilemap layer rendering, including scroll.
    [sharpie-hw.kicad_pcb]
2025-09-11 PCB changes of some kind: appears to be the version sent to JLC.
    The manufactured version of the PCB has no voltage divider or battery input,
    because they were unnecssary (and in the case of the battery input,
    unsafe).
    [mcu.kicad_sch, power.kicad_sch, sharpie-hw.kicad_pcb]
2025-09-24 Add sharpie-cad including sharpie-carrier.FCStd for putting the whole thing on.
    [sharpie-carrier.FCStd]
2025-09-28 Add sharpie-sw, currently configured to use 3 PIO blocks (untested).
    Using and reusing one PIO and two DMAs makes it...not work, in ways
    I can't figure out. Using 3 PIOs and 6 DMAs might make it work.
    [sharpie-carrier.FCStd]
2025-09-28 Add sharpie-cad, including super basic board+screen carrier.
    [sharpie-carrier-Body.3mf]
2025-09-29 sharpie-sw generates proper waveforms, but the display still doesn't work.
    The issue was that the zeros DMA stream was configured to send twice
    as much data as it's supposed to, so it never finished, and everything
    afterward got messed up.
    [main.c]
2025-10-02 Add sharpie-hw-rev2. The version in this commit is the one sent to production.
    [RP2350_QFN60.step, mcu.kicad_sch, power.kicad_sch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]
2025-12-19 Add partial update code, which makes correct waveforms but doesn't quite work.
    Main sharpie-sw code also stopped working after adding the partial code, even
    when it doesn't run.
    [main.c]
2025-12-19 Fix partial update SM pin configuration and partial update works!
    [main.c]
2025-12-22 Make INTB fall after irq set from GCK end SM instead of on a timer.
2025-12-24 Fix partial updates that begin at the top of the frame.
    These start at GCK2, like in a full update, so the GCK SM has to
    be able to take GCK2 into the main loop.
    [main.c]
2025-12-31 Move VA/VB/VCOM to just PWM, no CPU involvement.
    Also delete sharpie-va-vb-vcom.pio, which was way overkill for VA/VB/VCOM.
2026-01-02 Correct GCK changed lows to fix overall timing.
    Also add note about initial changed section counter not needing the -1
    that the rest of them do.
    [main.c]
2026-01-04 Major refactor of main.c and fix extra GEN if partial frame starts with changes.
    [main.c]
2026-02-12 Add videos to README and 3D rendering of PCB to sharpie-hw-rev2.
